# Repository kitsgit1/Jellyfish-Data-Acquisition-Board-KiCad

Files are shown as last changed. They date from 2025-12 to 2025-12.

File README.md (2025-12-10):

# Jellyfish Data Acquisition Board KiCad PCB Files
This is one of 3 repositories related to the Jellyfish Data Acquisition project. The goal is to build the hardware for a noninvasive electrode array capable of detecting neronal activity of small jellyfish, the firmware to digitize the signals and control the multiplexing of each pixel, and the software to control the system and graph the data.
| **Hardware** <br/> (You Are Here) | Firmware | Software |
| --- | --- | --- |
| <br/>https://github.com/kitsgit1/Jellyfish-Data-Acquisition-Board-KiCad |  <br/>https://github.com/kitsgit1/Jellyfish-Data-Acquisition-STM32 |  <br/>https://github.com/kitsgit1/Jellyfish-Data-Display-GUI |

# Hardware Documentation - Rev A
There are two boards that make up the assembly: the Electrode board and the Digitizer board.
## Jellyfish Electrode Board
The electrode board is responsible for interfacing with the jellyfish and multiplexing all pixels down to one wire using low charge-injection analog mux's. There is an optional path for a front-end buffer amplifier (non-inverting x2 gain for Rf = Rg). I/O consists of the Guard signal which drives the saltwater bath to the same potential as the op-amp reference voltage, the digital I/O to control the shift registers that select the correct pixel through setting all the multiplexers, and the single analog switched electrode signal.

## Jellyfish Digitizer Board
The digitizer board further amplifies the tiny signal from the electrode board into something the STM32's 10MHz/12-bit ADC can handle. The STM32 is also responsible for collecting, storing, and sending data to either the PC over USB or to an SD card.

Details to come...

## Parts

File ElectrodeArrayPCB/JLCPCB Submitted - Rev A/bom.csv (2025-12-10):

Designator | Footprint | Quantity | Value | LCSC Part #
BT1 | AMASS_XT30PW-M_1x02_P2.50mm_Horizontal | 1 | XT30PW-M30.G.Y | C431092
C1, C13, C14, C15, C18, C20, C22, C23, C24, C25, C30, C36, C38, C39, C41, C42, C43, C46, C51, C52, C53, C54, C55, C56, C59, C6, C63, C64, C68, C7, C70, C72, C73, C8, C9 | C_0402 | 35 | 100nF | C307331
C10, C11, C12, C16, C28, C67, C69, C71, C77, C79, C80 | C_1206 | 11 | 47uF | C96123
C17, C2, C21, C26, C29, C32, C4, C5, C76 | C_0805 | 9 | 10uF | C15850
C19, C44, C45, C78 | C_0402 | 4 | 10pF | C32949
C27, C3, C58, C81 | C_0402 | 4 | 4.7uF | C23733
C31, C37, C40, C57, C60 | C_0402 | 5 | 1uF | C52923
C61, C62 | C_0603 | 2 | 2.2uF | C23630
C65, C66 | C_0402 | 2 | 470pF | C1537
C74, C75 | C_0402 | 2 | 20pF | C1554
D1, D2, D3 | D_0603 | 3 | Red | C2286
FB1, FB2, FB3, FB4 | FB_0805 | 4 | ~ | C1015
J1 | PinHeader_2x05_P1.27mm_Vertical_SMD | 1 | HX PZ1.27-2x5P TP
J11, J3, J7, J8, J9 | SMA_Wurth_60312102114405_Vertical | 5 | KH-SMAK-SMT
J12 | PinHeader_1x03_P2.54mm_Vertical | 1 | 2.54-1*3PPin | C49257
J4 | microSD_HC_Molex_104031-0811 | 1 | 1040310811 | C585350
J6 | TYPE-C-SMD_HX-TYPE-C-16PIN | 1 | Connector, USB-TYPE-C-16P | C2927039
R1, R105, R19, R22, R32, R36, R47, R7, R89, R97, R98, R99 | R_0402 | 12 | 1kΩ | C11702
R10, R101, R107, R109, R11, R110, R111, R113, R114, R115, R116, R117, R120, R15, R16, R17, R18, R20, R21, R23, R24, R27, R28, R30, R31, R35, R37, R43, R44, R45, R52, R53, R55, R56, R57, R58, R71, R78, R85, R86, R87, R88, R92, R95, R96 | R_0402 | 45 | 0Ω | C17168
R100, R106, R13 | R_0402 | 3 | 49.9Ω | C25120
R102, R51, R8 | R_1206 | 3 | 0Ω | C17888
R103, R34, R4 | R_0402 | 3 | 10kΩ | C25744
R104, R94 | R_0603 | 2 | 5.1kΩ | C23186
R108 | R_0402 | 1 | 1Ω | C25086
R112 | R_0805 | 1 | 0Ω | C17477
R118, R3, R42, R46, R90, R91 | R_0402 | 6 | 100kΩ | C25741
R119, R2, R29, R49, R5, R54 | R_0603 | 6 | 270kΩ | C22965
R12 | R_0402 | 1 | 33kΩ | C25779
R14, R26 | R_0402 | 2 | 100Ω | C25076
R25, R50, R6 | R_0402 | 3 | 12kΩ | C25752
R33, R39 | R_0402 | 2 | 470kΩ | C25790
R38 | R_0402 | 1 | 220kΩ | C25767
R40, R93 | R_0402 | 2 | 1MΩ | C26083
R41, R59, R60, R61, R62, R63, R64 | R_0402 | 7 | 47kΩ | C25792
R48, R9 | R_0402 | 2 | 22kΩ | C25768
R65, R66, R67, R68, R69, R70, R72, R73, R74, R75, R76, R77, R79, R80, R81, R82, R83, R84 | R_0402 | 18 | 10Ω | C25077
S1 | SW_TS-1088-AR02016 | 1 | Tactile Button, 160gf | C720477
TP1, TP2, TP5, TP6, TP7 | TestPoint_Loop_D2.54mm_Drill1.5mm_Beaded | 5 | RH-5000 | C5277086
TP10, TP11, TP12, TP13, TP14, TP4, TP8, TP9 | TestPoint_Loop_D2.54mm_Drill1.5mm_Beaded | 8 | RH-5001 | C5199801
TP3 | TestPoint_Loop_D2.54mm_Drill1.5mm_Beaded | 1 | RH-5001
U1, U28, U4 | VSON-10-1EP_3x3mm_P0.5mm_EP1.65x2.4mm_ThermalVias | 3 | TPS7A9401DSCR | C5220127
U10 | SOT-23-5 | 1 | REF2033AIDDCR | C440747
U11 | SOIC-8_3.9x4.9mm_P1.27mm | 1 | LMP7721
U12 | SOT-23-5 | 1 | LMP7715
U14 | LFCSP-16-1EP_3x3mm_P0.5mm_EP1.3x1.3mm_ThermalVias | 1 | ADA4940-1ACPZ-R2 | C654337
U15 | LQFP-100_14x14mm_P0.5mm | 1 | STM32H7B0VBT6 | C730227
U16, U17 | SOT-23-6 | 2 | OPA847IDBVR | C160422
U19 | TSSOP-16_4.4x5mm_P0.65mm | 1 | TMUX1108PW
U2, U3 | PinHeader_03x03_0.1in | 2 | HX PZ2.54-3x3P ZZ | C32713290
U24, U25 | SOIC-8_3.9x4.9mm_P1.27mm | 2 | APS6404L-3SQR-SN | C5333729
U27 | SOIC-8_L4.9-W3.9-P1.27-LS6.0-BL | 1 | REF5025AIDR
U5 | SSOP-24_5.3x8.2mm_P0.65mm | 1 | 74HC4067PW,118 | C179326
U9 | SOT-23-3_L2.9-W1.6-P1.90-LS2.8-BR | 1 | CJ431 | C3113
X1 | OSC-SMD_4P-L3.2-W2.5-BL | 1 | X322516MLB4SI | C13738

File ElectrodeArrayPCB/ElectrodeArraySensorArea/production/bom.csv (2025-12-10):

Designator | Footprint | Quantity | Value | LCSC Part #
C1, C11, C13, C14, C16, C19, C21, C5, C6, C8, C9 | C_0402 | 11 | 100nF | C307331
C10, C12, C15, C17, C18, C3, C4, C7 | C_0402 | 8 | 47pF | C1567
C2 | C_0805 | 1 | 10uF | C15850
C20 | C_1206 | 1 | 47uF | C96123
C78 | C_0402 | 1 | 10pF | C32949
FB1 | FB_0805 | 1 | ~ | C1015
R20, R31, R9 | R_0402 | 3 | 0Ω | C17168
R4 | R_0402 | 1 | 10kΩ | C25744
U1 | Electrode_Array_64_Square | 1 | ~
U10, U11, U12, U13, U14, U15, U16, U17, U18 | UQFN-16_1.8x2.6mm_P0.4mm | 9 | TMUX1108RSVR
U19, U20, U21, U22, U8, U9 | PinHeader_1x03_P2.54mm_Vertical | 6 | DS1023-1x3SF11 | C7509516
U2, U3, U4, U5, U6 | DHVQFN-16-1EP_2.5x3.5mm_P0.5mm_EP1x2mm | 5 | SN74LV595ABQBR | C7083313
U7 | SOIC-8_3.9x4.9mm_P1.27mm | 1 | LMP7721

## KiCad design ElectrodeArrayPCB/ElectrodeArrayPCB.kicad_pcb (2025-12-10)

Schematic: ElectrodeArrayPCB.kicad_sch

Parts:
BT1: XT30PW-M30.G.Y; AMASS_XT30PW-M_1x02_P2.50mm_Horizontal; LCSC C431092
C1, C6, C7, C8, C9, C13, C14, C15, C18, C20, C22, C23, C24, C25, C30, C36, C38, C39, C41, C42, C43, C46, C51, C52, C53, C54, C55, C56, C59, C63, C64, C68, C70, C72, C73: 100nF; C_0402; Voltage Rated 50V; Tolerance ±10%; Part CL05B104KB54PNC; LCSC C307331
C2, C4, C5, C17, C21, C26, C29, C32, C76: 10uF; C_0805; Voltage Rated 25V; Tolerance ±10%; Part CL21A106KAYNNNE; LCSC C15850
C3, C27, C58, C81: 4.7uF; C_0402; Voltage Rated 10V; Tolerance ±20%; Part CL05A475MP5NRNC; LCSC C23733
C10, C11, C12, C16, C28, C67, C69, C71, C77, C79, C80: 47uF; C_1206; Voltage Rated 10V; Tolerance ±20%; Part CL31A476MPHNNNE; LCSC C96123
C19, C44, C45, C78: 10pF; C_0402; Voltage Rated 50V; Tolerance ±5%; Part CL05C100JB5NNNC; LCSC C32949
C31, C37, C40, C57, C60: 1uF; C_0402; Voltage Rated 25V; Tolerance ±10%; Part CL05A105KA5NQNC; LCSC C52923
C61, C62: 2.2uF; C_0603; Voltage Rated 16V; Tolerance ±10%; Part CL10A225KO8NNNC; LCSC C23630
C65, C66: 470pF; C_0402; Voltage Rated 50V; Tolerance ±10%; Part 0402B471K500NT; LCSC C1537
C74, C75: 20pF; C_0402; Voltage Rated 50V; Tolerance ±5%; Part 0402CG200J500NT; LCSC C1554
D1, D2, D3: Red; D_0603; Part KT-0603R; LCSC C2286
FB1, FB2, FB3, FB4: FB_0805; Current Rating 800mA; Tolerance ±25%; Part GZ2012D101TF; LCSC C1015
J1: HX PZ1.27-2x5P TP; PinHeader_2x05_P1.27mm_Vertical_SMD
J2, J10: Conn_01x10_Pin; Electrode_Line_8_Test
J3, J7, J8, J9, J11: KH-SMAK-SMT; SMA_Wurth_60312102114405_Vertical
J4: 1040310811; microSD_HC_Molex_104031-0811; LCSC C585350
J5: Conn_ARM_SWD_TagConnect_TC2030; Tag-Connect_TC2030-IDC-FP_2x03_P1.27mm_Vertical
J6: Connector, USB-TYPE-C-16P; TYPE-C-SMD_HX-TYPE-C-16PIN; LCSC C2927039
J12: 2.54-1*3PPin; PinHeader_1x03_P2.54mm_Vertical; LCSC C49257
P1, P2: Jumper Shunt; LCSC C2758458
R1, R7, R19, R22, R32, R36, R47, R89, R97, R98, R99, R105: 1kΩ; R_0402; Overload Voltage (Max) 50V; Tolerance ±1%; Part 0402WGF1001TCE; LCSC C11702
R2, R5, R29, R49, R54, R119: 270kΩ; R_0603; Overload Voltage (Max) 75V; Tolerance ±1%; Part 0603WAF2703T5E; LCSC C22965
R3, R42, R46, R90, R91, R118: 100kΩ; R_0402; Overload Voltage (Max) 50V; Tolerance ±1%; Part 0402WGF1003TCE; LCSC C25741
R4, R34, R103: 10kΩ; R_0402; Overload Voltage (Max) 50V; Tolerance ±1%; Part 0402WGF1002TCE; LCSC C25744
R6, R25, R50: 12kΩ; R_0402; Overload Voltage (Max) 50V; Tolerance ±1%; Part 0402WGF1202TCE; LCSC C25752
R8, R51, R102: 0Ω; R_1206; Overload Voltage (Max) 200V; Tolerance ±1%; Part 1206W4F0000T5E; LCSC C17888
R9, R48: 22kΩ; R_0402; Overload Voltage (Max) 50V; Tolerance ±1%; Part 0402WGF2202TCE; LCSC C25768
R10, R11, R17, R18, R20, R21, R23, R27, R28, R30, R31, R35, R37, R44, R45, R53, R55, R58, R71, R78, R85, R86, R87, R88, R92, R95, R107, R109, R110, R111, R113, R114, R115, R120: 0Ω; R_0402; Overload Voltage (Max) 50V; Tolerance ±1%; Part 0402WGF0000TCE; LCSC C17168
R12: 33kΩ; R_0402; Overload Voltage (Max) 50V; Tolerance ±1%; Part 0402WGF3302TCE; LCSC C25779
R13, R100, R106: 49.9Ω; R_0402; Overload Voltage (Max) 50V; Tolerance ±1%; Part 0402WGF499JTCE; LCSC C25120
R14, R26: 100Ω; R_0402; Overload Voltage (Max) 50V; Tolerance ±1%; Part 0402WGF1000TCE; LCSC C25076
R15, R16, R24, R43, R52, R56, R57, R96, R101, R116, R117: 0Ω; R_0402; Overload Voltage (Max) 50V; Tolerance ±1%; Part 0402WGF0000TCE; LCSC C17168; not fitted
R33, R39: 470kΩ; R_0402; Overload Voltage (Max) 50V; Tolerance ±1%; Part 0402WGF4703TCE; LCSC C25790
R38: 220kΩ; R_0402; Overload Voltage (Max) 50V; Tolerance ±1%; Part 0402WGF2203TCE; LCSC C25767
R40, R93: 1MΩ; R_0402; Overload Voltage (Max) 50V; Tolerance ±1%; Part 0402WGF1004TCE; LCSC C26083
R41, R59, R60, R61, R62, R63, R64: 47kΩ; R_0402; Overload Voltage (Max) 50V; Tolerance ±1%; Part 0402WGF4702TCE; LCSC C25792
R65, R66, R67, R68, R69, R70, R72, R73, R74, R75, R76, R77, R79, R80, R81, R82, R83, R84: 10Ω; R_0402; Overload Voltage (Max) 50V; Tolerance ±1%; Part 0402WGF100JTCE; LCSC C25077
R94, R104: 5.1kΩ; R_0603; Overload Voltage (Max) 75V; Tolerance ±1%; Part 0603WAF5101T5E; LCSC C23186
R108: 1Ω; R_0402; Overload Voltage (Max) 50V; Tolerance ±1%; Part 0402WGF100KTCE; LCSC C25086
R112: 0Ω; R_0805; Overload Voltage (Max) 150V; Tolerance ±1%; Part 0805W8F0000T5E; LCSC C17477
S1: Tactile Button, 160gf; SW_TS-1088-AR02016; Voltage Rating (Dc) 12V; Part TS-1088-AR02016; LCSC C720477
TP1, TP2, TP5, TP6, TP7: RH-5000; TestPoint_Loop_D2.54mm_Drill1.5mm_Beaded; LCSC C5277086
TP3: RH-5001; TestPoint_Loop_D2.54mm_Drill1.5mm_Beaded
TP4, TP8, TP9, TP10, TP11, TP12, TP13, TP14: RH-5001; TestPoint_Loop_D2.54mm_Drill1.5mm_Beaded; LCSC C5199801
U1, U4, U28: TPS7A9401DSCR; VSON-10-1EP_3x3mm_P0.5mm_EP1.65x2.4mm_ThermalVias; LCSC C5220127
U2, U3: HX PZ2.54-3x3P ZZ; PinHeader_03x03_0.1in; LCSC C32713290
U5: 74HC4067PW,118; SSOP-24_5.3x8.2mm_P0.65mm; LCSC C179326
U9: CJ431; SOT-23-3_L2.9-W1.6-P1.90-LS2.8-BR; Output Voltage 2.5V~36V; Tolerance ±0.5%; Part CJ431; LCSC C3113
U10: REF2033AIDDCR; SOT-23-5; LCSC C440747
U11: LMP7721; SOIC-8_3.9x4.9mm_P1.27mm
U12: LMP7715; SOT-23-5
U14: ADA4940-1ACPZ-R2; LFCSP-16-1EP_3x3mm_P0.5mm_EP1.3x1.3mm_ThermalVias; LCSC C654337
U15: STM32H7B0VBT6; LQFP-100_14x14mm_P0.5mm; LCSC C730227
U16, U17: OPA847IDBVR; SOT-23-6; LCSC C160422
U19: TMUX1108PW; TSSOP-16_4.4x5mm_P0.65mm
U24, U25: APS6404L-3SQR-SN; SOIC-8_3.9x4.9mm_P1.27mm; LCSC C5333729
U27: REF5025AIDR; SOIC-8_L4.9-W3.9-P1.27-LS6.0-BL
X1: X322516MLB4SI; OSC-SMD_4P-L3.2-W2.5-BL; Frequency Tolerance ±10ppm; Part X322516MLB4SI; LCSC C13738

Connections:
+3.3V: R8.2, R52.2, R112.1
+3.3VA: FB2.2, R51.2
+5V: C9.1, C16.1, R14.2, R18.1, R19.1, R27.2, R30.2, R37.2, R44.1, R45.1, R85.2, R102.2, R109.2, U3.1
/MCU_VDD33: C51.1, C52.1, C53.1, C54.1, C55.1, C56.1, C57.1, C58.1, R58.1, R71.1, R78.1, R89.1, R92.2, R112.2, U15.6 (VBAT), U15.11 (VDD), U15.27 (VDD), U15.50 (VDD), U15.75 (VDD), U15.100 (VDD)
/PA11_USB_DM: J6.A7 (D-), J6.B7 (D-), U15.70 (PA11)
/PA12_USB_DP: J6.A6 (D+), J6.B6 (D+), U15.71 (PA12)
/USART1_RX: J12.2, U15.54 (PB15)
/USART1_TX: J12.1, U15.53 (PB14)
/amp_inverting_input: R34.1, U12.3 (+)
/battery: BT1.1 (+), C20.1, C21.1, FB1.1, FB3.1, FB4.1
/grd_drv_out: R26.2, U12.1, U12.4 (-)
/ldo_3v3: C10.1, C17.1, C18.1, R5.2, R8.1, TP2.1, U1.8 (SNS), U1.9 (OUT), U1.10 (OUT)
/ldo_3v3A: C28.1, C29.1, C30.1, R49.2, R51.1, TP7.1, U4.8 (SNS), U4.9 (OUT), U4.10 (OUT)
/ldo_5v: C4.1, C7.1, C80.1, R54.2, R102.1, TP1.1, U28.8 (SNS), U28.9 (OUT), U28.10 (OUT)
/vbat_post_fb5: C5.1, C6.1, FB3.2, R1.2, R119.1, U28.1 (IN), U28.2 (IN)
/vbat_post_fb33: C1.1, C2.1, FB1.2, R2.1, R7.1, U1.1 (IN), U1.2 (IN)
/vbat_post_fb33A: C22.1, C26.1, FB4.2, R29.1, R47.1, U4.1 (IN), U4.2 (IN)
ADC_N: R100.2, R114.1
ADC_P: R106.2, R113.1
GND: BT1.2 (-), C1.2, C2.2, C3.2, C4.2, C5.2, C6.2, C7.2, C8.2, C9.2, C10.2, C11.2, C12.2, C13.2, C14.2, C15.2, C16.2, C17.2, C18.2, C19.1, C20.2, C21.2, C22.2, C23.2, C24.2, C25.2, C26.2, C27.2, C28.2, C29.2, C30.2, C31.2, C32.2, C36.2, C37.2, C38.2, C39.2, C40.2, C41.2, C42.1, C43.2, C44.2, C45.1, C46.2, C51.2, C52.2, C53.2, C54.2, C55.2, C56.2, C57.2, C58.2, C59.2, C60.2, C61.2, C62.2, C63.2, C64.2, C68.2, C69.2, C70.2, C71.2, C72.2, C73.2, C76.2, C77.2, C79.2, C80.2, C81.2, J3.2 (Ext), J4.6 (VSS), J4.9 (SHIELD), J5.5 (GND), J6.A12B1 (GND), J6.B12A1 (GND), J7.2 (Ext), J8.2 (Ext), J9.2 (Ext), J11.2 (Ext), J12.3, R3.2, R6.2, R9.2, R12.2, R13.2, R15.2, R17.1, R24.1, R25.2, R46.2, R48.2, R50.2, R93.2, R94.2, R104.2, R107.2, R108.2, R116.1, R117.2, R118.2, S1.1 (A), TP3.1, TP4.1, TP8.1, TP9.1, TP10.1, TP11.1, U1.6 (GND), U1.11 (EPAD), U2.1, U2.3, U2.7, U2.9, U3.2, U3.4, U3.5, U4.6 (GND), U4.11 (EPAD), U5.12 (GND), U5.13 (S3), U5.15 (~E), U9.3 (AN), U10.2 (GND), U11.3 (V-), U12.2 (V-), U14.13 (-Vs), U14.14 (-Vs), U14.15 (-Vs), U14.16 (-Vs), U14.17 (EP), U15.10 (VSS), U15.19 (VSSA), U15.26 (VSS), U15.49 (VSS), U15.74 (VSS), U15.99 (VSS), U16.2 (V-), U17.2 (V-), U19.3 (VSS), U19.14 (GND), U24.4 (VSS), U25.4 (VSS), U27.4 (GND), U28.6 (GND), U28.11 (EPAD), X1.2 (GND), X1.4 (GND)
unnamed: C14.1, C67.1, P2.2, R23.1, R53.1, R101.2
unnamed: C41.1, C76.1, R85.1, R95.2, U14.5 (+Vs), U14.6 (+Vs), U14.7 (+Vs), U14.8 (+Vs)
unnamed: C61.1, C62.1, C63.1, C64.1, U15.48 (VCAP), U15.73 (VCAP)
unnamed: C65.2, C66.1, R107.1
unnamed: C67.2, R108.1
unnamed: D1.2, R1.1
unnamed: D2.2, R7.2
unnamed: D3.2, R47.2
unnamed: J1.1, R40.2, R43.2
unnamed: J1.3, R39.2
unnamed: J1.5, R38.2
unnamed: J1.7, R42.2
unnamed: J1.9, P1.1, R41.2
unnamed: J1.2, J1.4, J1.6, J1.8, J1.10, P1.2, R43.1, R55.1, R56.1, R105.1
unnamed: J2.1, U5.9 (I0)
unnamed: J2.2, U5.8 (I1)
unnamed: J2.3, U5.7 (I2)
unnamed: J2.4, U5.6 (I3)
unnamed: J2.5, U5.5 (I4)
unnamed: J2.6, U5.4 (I5)
unnamed: J2.7, U5.3 (I6)
unnamed: J2.8, U5.2 (I7)
unnamed: J2.9, J8.1 (In)
unnamed: J3.1 (In), R20.1
unnamed: J4.5 (CLK), R64.2, R69.2
unnamed: J4.3 (CMD), R63.2, R70.2
unnamed: J4.7 (DAT0), R60.2, R65.2
unnamed: J4.8 (DAT1), R61.2, R66.2
unnamed: J4.1 (DAT2), R59.2, R67.2
unnamed: J4.2 (DAT3/CD), R62.2, R68.2
unnamed: C36.1, J4.4 (VDD), R58.2, R59.1, R60.1, R61.1, R62.1, R63.1, R64.1
unnamed: J5.4 (SWCLK), R87.1
unnamed: J5.2 (SWDIO), R88.2
unnamed: J5.1 (VCC), R91.1, R92.1
unnamed: J5.3 (~RESET), R86.1
unnamed: J6.A5 (CC1), R104.1
unnamed: J6.B5 (CC2), R94.1
unnamed: C46.1, J6.S1 (SHIELD), R93.1
unnamed: J6.A9B4 (VBUS), J6.B9A4 (VBUS), R96.1
unnamed: J7.1 (In), R120.2
unnamed: C19.2, J9.1 (In), R10.2, R11.2
unnamed: J10.1, U19.4 (S1)
unnamed: J10.2, U19.5 (S2)
unnamed: J10.3, U19.6 (S3)
unnamed: J10.4, U19.7 (S4)
unnamed: J10.5, U19.9 (S8)
unnamed: J10.6, U19.10 (S7)
unnamed: J10.7, U19.11 (S6)
unnamed: J10.8, U19.12 (S5)
unnamed: J2.10, J10.9
unnamed: J10.10, R13.1
unnamed: J11.1 (In), R28.2
unnamed: R21.2, U2.5
unnamed: R28.1, R55.2, U17.1
unnamed: R56.2, R57.1
unnamed: R17.2, R52.1, R103.1
unnamed: R33.2, R35.2, R57.2, R115.1
unnamed: R115.2, U16.1
unnamed: C42.2, R90.1, S1.2 (B)
unnamed: R2.2, R3.1, U1.3 (EN_UV)
unnamed: R5.1, R6.1, U1.5 (FB_PG)
unnamed: C3.1, R9.1, U1.7 (NR/SS)
unnamed: D2.1, U1.4 (PG)
unnamed: R29.2, R46.1, U4.3 (EN_UV)
unnamed: R49.1, R50.1, U4.5 (FB_PG)
unnamed: C27.1, R48.1, U4.7 (NR/SS)
unnamed: D3.1, U4.4 (PG)
unnamed: R10.1, U5.1 (COM)
unnamed: C8.1, R44.2, U5.24 (VCC)
unnamed: R16.1, R19.2, R101.1, U9.2 (CAT)
unnamed: R15.1, R16.2, U9.1 (REF)
unnamed: C70.1, C71.1, R109.1, U10.3 (EN), U10.4 (IN)
unnamed: C72.1, R110.1, U10.1 (Vbias)
unnamed: C73.1, R111.1, U10.5 (Vref)
unnamed: R20.2, U11.1 (IN+)
unnamed: C78.1, R4.1, R22.1, R34.2, U11.8 (IN-)
unnamed: C11.1, C12.1, C13.1, R27.1, U11.6 (V+)
unnamed: C78.2, R4.2, R31.2, U11.4 (Vout)
unnamed: C15.1, C77.1, C79.1, R14.1, U12.5 (V+)
unnamed: C74.2, R99.2, U14.4 (+FB)
unnamed: C75.1, R97.1, R105.2, U14.2 (+IN)
unnamed: R113.2, U14.10 (+OUT)
unnamed: C75.2, R97.2, U14.1 (-FB)
unnamed: C74.1, R98.2, R99.1, U14.3 (-IN)
unnamed: R114.2, U14.11 (-OUT)
unnamed: R110.2, U14.9 (VOCM)
unnamed: R95.1, U14.12 (~DISABLE)
unnamed: R103.2, U15.94 (BOOT0)
unnamed: R96.2, U15.68 (PA9)
unnamed: R88.1, R91.2, U15.72 (PA13)
unnamed: R87.2, U15.76 (PA14)
unnamed: C65.1, R100.1, U15.17 (PC2_C)
unnamed: C66.2, R106.1, U15.18 (PC3_C)
unnamed: R65.1, U15.65 (PC8)
unnamed: R66.1, U15.66 (PC9)
unnamed: R67.1, U15.78 (PC10)
unnamed: R68.1, U15.79 (PC11)
unnamed: R69.1, U15.80 (PC12)
unnamed: R81.1, U15.58 (PD11)
unnamed: R82.1, U15.59 (PD12)
unnamed: R84.1, U15.60 (PD13)
unnamed: R73.2, U15.37 (PE7)
unnamed: R74.2, U15.38 (PE8)
unnamed: R75.2, U15.39 (PE9)
unnamed: R76.2, U15.40 (PE10)
unnamed: R72.1, R79.1, U15.41 (PE11)
unnamed: C45.2, U15.12 (PH0), X1.3 (OSC)
unnamed: C44.1, U15.13 (PH1), X1.1 (OSC)
unnamed: C59.1, C60.1, FB2.1, U15.21 (VDDA)
unnamed: R21.1, R31.1, R120.1, U16.3 (+)
unnamed: R32.1, R33.1, U16.4 (-)
unnamed: C23.1, R30.1, U16.6 (V+)
unnamed: R116.2, U16.5 (~DIS)
unnamed: R35.1, U17.3 (+)
unnamed: R36.1, R38.1, R39.1, R40.1, R41.1, R42.1, U17.4 (-)
unnamed: C24.1, R37.1, U17.6 (V+)
unnamed: R117.1, U17.5 (~DIS)
unnamed: R11.1, U19.8 (D)
unnamed: C25.1, R45.2, U19.2 (EN), U19.13 (VDD)
unnamed: R77.2, U24.6 (SCLK)
unnamed: R75.1, U24.3 (SIO2)
unnamed: R76.1, U24.7 (SIO3)
unnamed: R73.1, U24.5 (SI/SIO0)
unnamed: R74.1, U24.2 (SO/SIO1)
unnamed: C37.1, C38.1, R71.2, U24.8 (VDD)
unnamed: R72.2, U24.1 (~CE)
unnamed: R80.1, U25.6 (SCLK)
unnamed: R83.2, U25.3 (SIO2)
unnamed: R84.2, U25.7 (SIO3)
unnamed: R81.2, U25.5 (SI/SIO0)
unnamed: R82.2, U25.2 (SO/SIO1)
unnamed: C39.1, C40.1, R78.2, U25.8 (VDD)
unnamed: R79.2, U25.1 (~CE)
unnamed: C31.1, C32.1, U27.5 (Trim/NR)
unnamed: C68.1, C69.1, R18.2, U27.2 (Vin)
unnamed: P2.1, R53.2, U27.6 (Vout)
unnamed: R118.1, R119.2, U28.3 (EN_UV)
unnamed: R25.1, R54.1, U28.5 (FB_PG)
unnamed: C81.1, R12.1, U28.7 (NR/SS)
unnamed: D1.1, U28.4 (PG)
PA7_OCTASPI_P1_IO2: R83.1, U15.31 (PA7)
PB2_OCTASPI_P1_CLK: R77.1, R80.2, U15.36 (PB2)
PD2_SDMMC1_CMD: R70.1, U15.83 (PD2)
STM32_RSTn: C43.1, R86.2, R89.2, R90.2, U15.14 (NRST)
Shift_OEb: U3.3, U15.28 (PA4)
Shift_RCLK: U3.6, U15.29 (PA5)
Shift_SER: U3.7, U15.33 (PC5)
Shift_SRCLK: U3.9, U15.32 (PC4)
Shift_SRCLRb: U3.8, U15.30 (PA6)
VCM_Guard_2.5V: R22.2, R23.2, R24.2, R32.2, R36.2, R98.1, TP5.1
Vref: R111.2, U15.20 (VREF+)
guard_ring: R26.1, TP6.1, U2.2, U2.4, U2.6, U2.8, U11.2 (GRD), U11.7 (GRD)
s0: TP14.1, U5.10 (S0), U15.1 (PE2), U19.1 (A0)
s1: TP13.1, U5.11 (S1), U15.2 (PE3), U19.16 (A1)
s2: TP12.1, U5.14 (S2), U15.3 (PE4), U19.15 (A2)

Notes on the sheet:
VCM=2.5V here
Alternate ram possibilities: APS12808L-3OBM-BA (128Mb OSPI, mouser) S70KL1281 (128Mb hyperam/OSPI, obsolete) W956A8MBYA5I (64Mb, LCSC stock, hyperbus) S66/67WVO32M8DALL/BLL (256Mb, OSPI)
16MHz
1.65V CM
1ms per AP spike (really 2-10ms) 20 points per spike -> 50us per sample -> 20kHz sample rate. 64 electrodes -> 1.28MHz sample rate. 4096 electrodes -> 81.92MHz sample rate, single CH. For now, pick ADC for 2MHz. High bit count.
DS Table 23

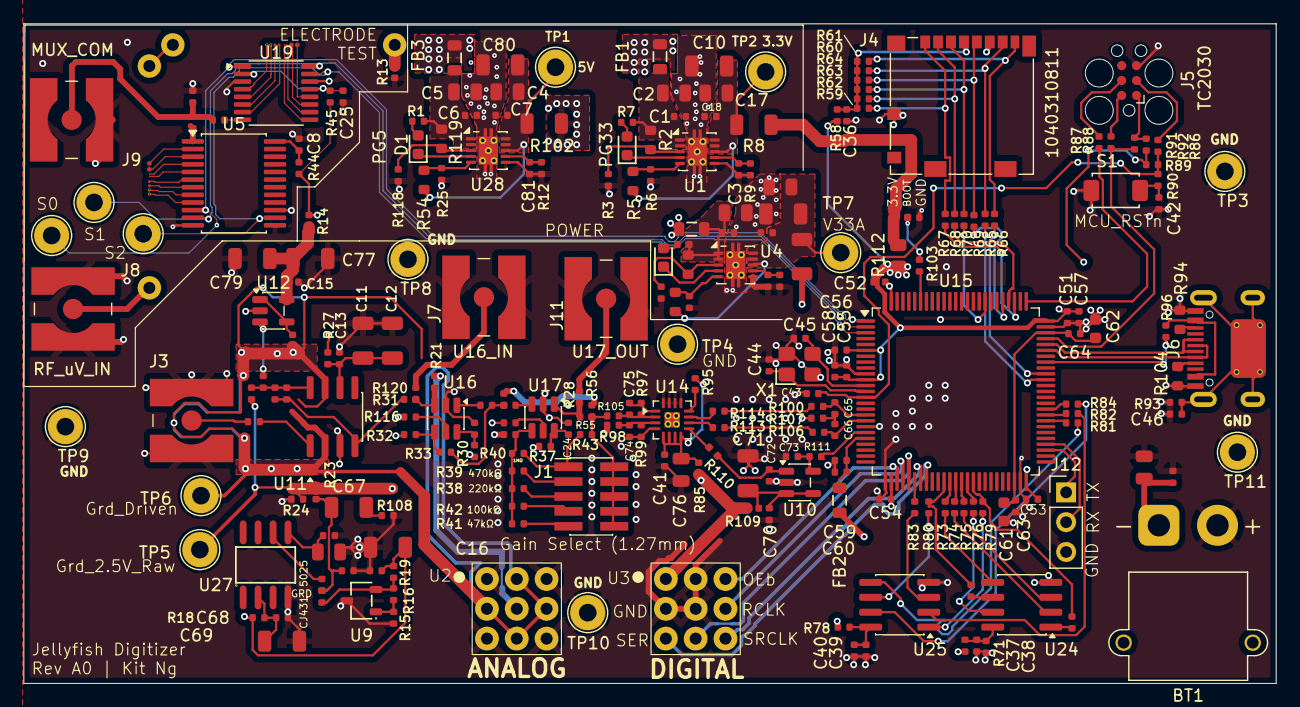
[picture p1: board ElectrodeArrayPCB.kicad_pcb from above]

Board: 4 copper layers, 106.7 x 56.2 mm, 248 parts (0 on the bottom side), 175 nets.

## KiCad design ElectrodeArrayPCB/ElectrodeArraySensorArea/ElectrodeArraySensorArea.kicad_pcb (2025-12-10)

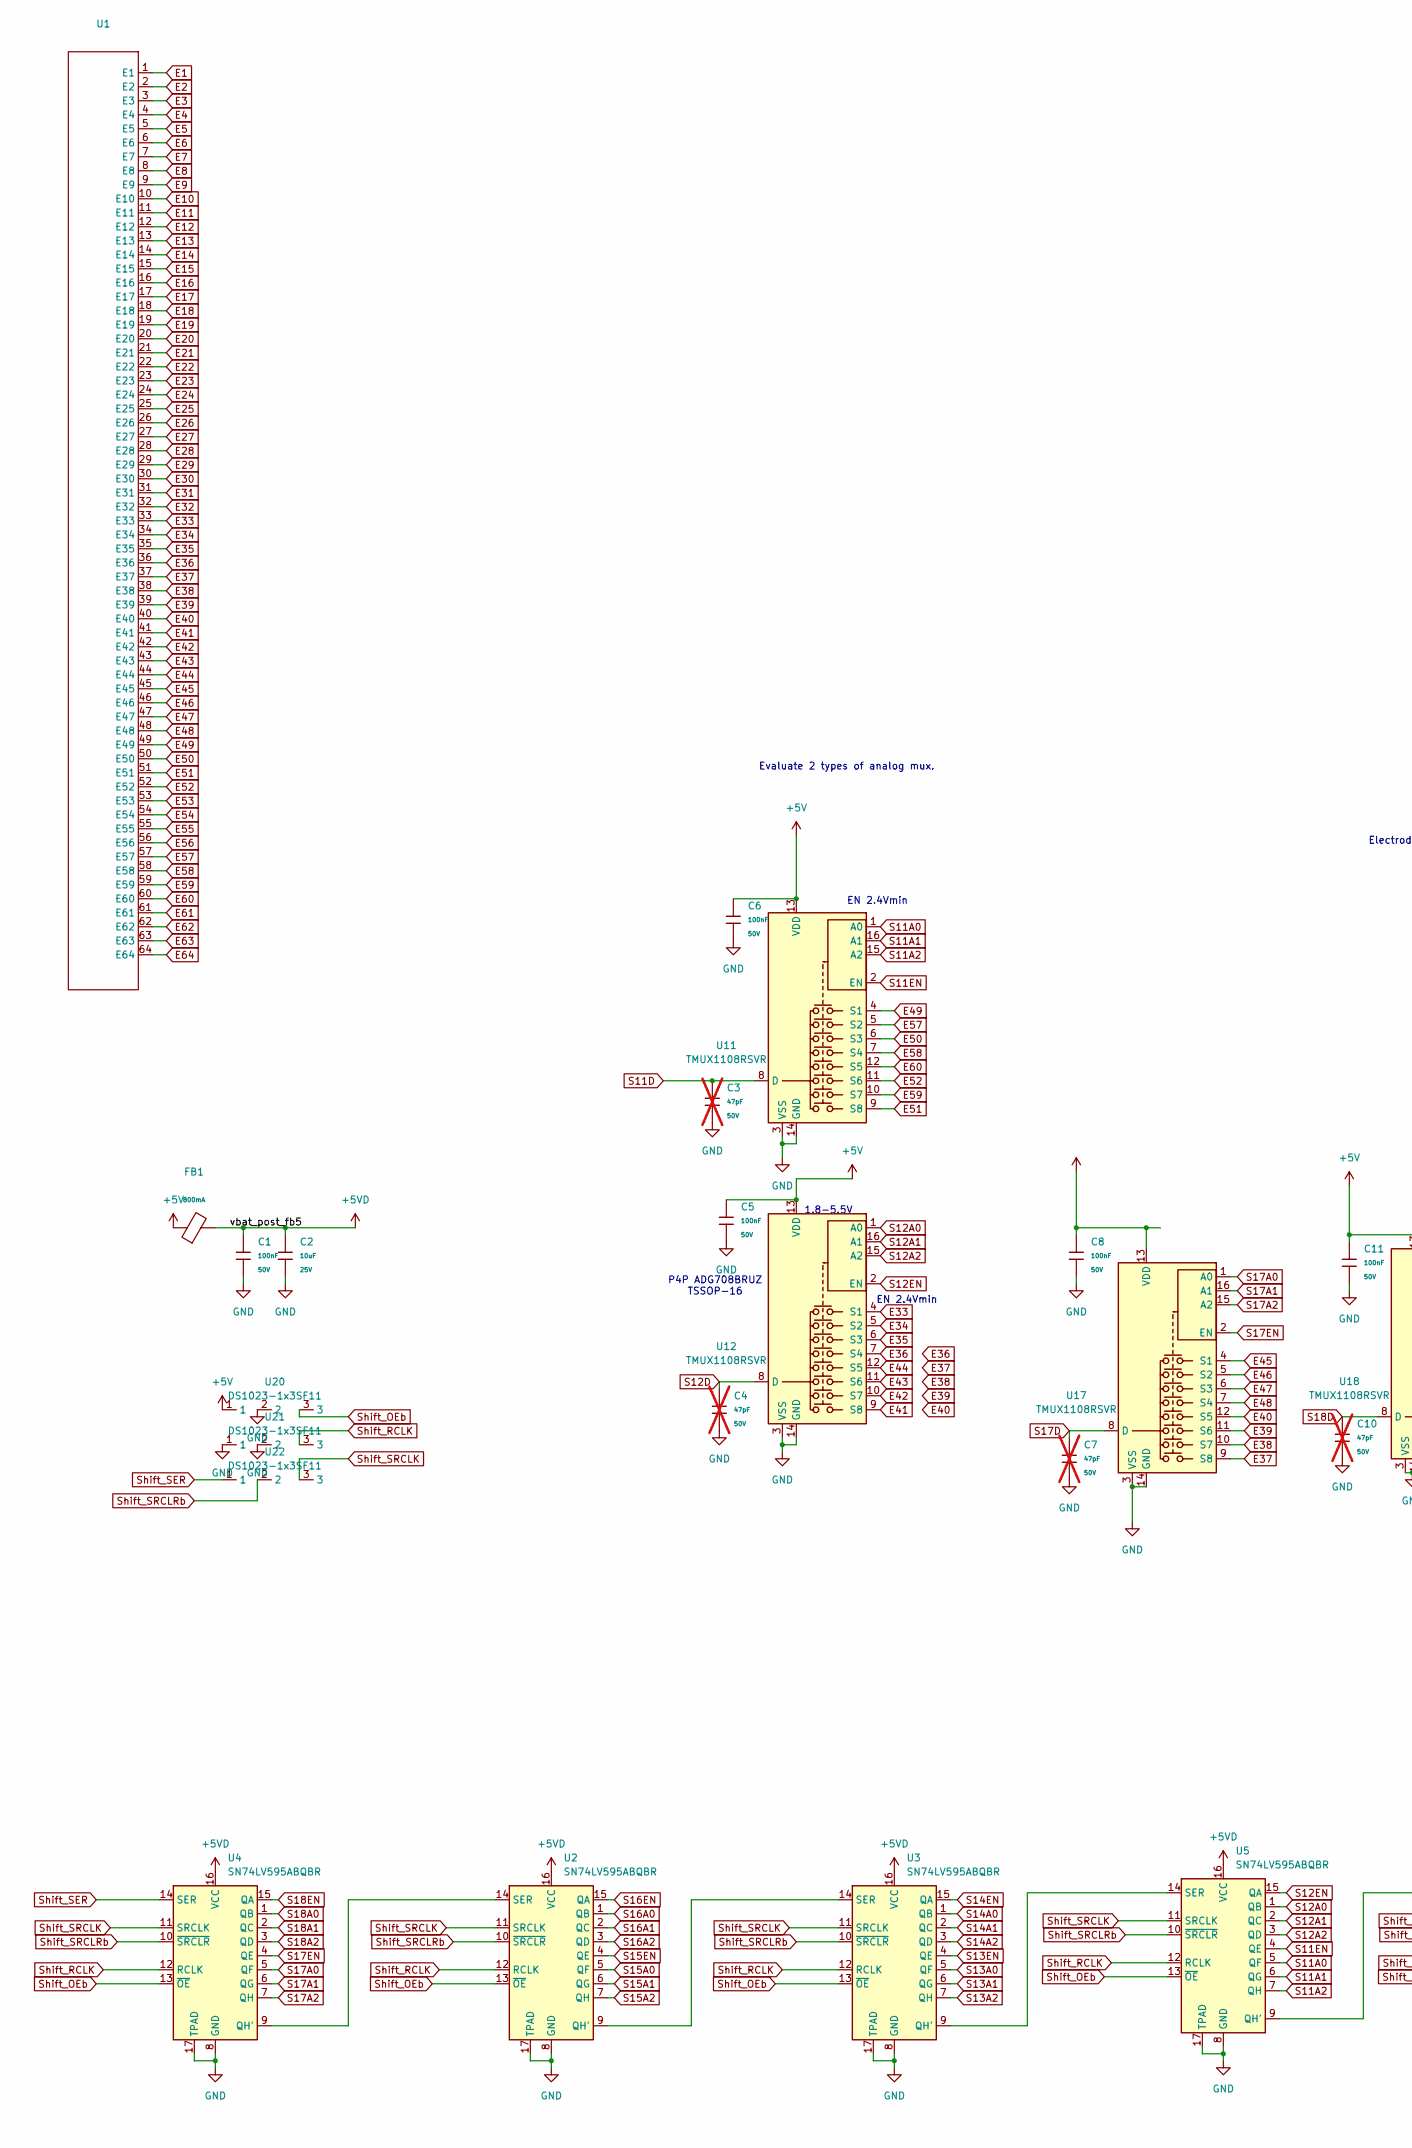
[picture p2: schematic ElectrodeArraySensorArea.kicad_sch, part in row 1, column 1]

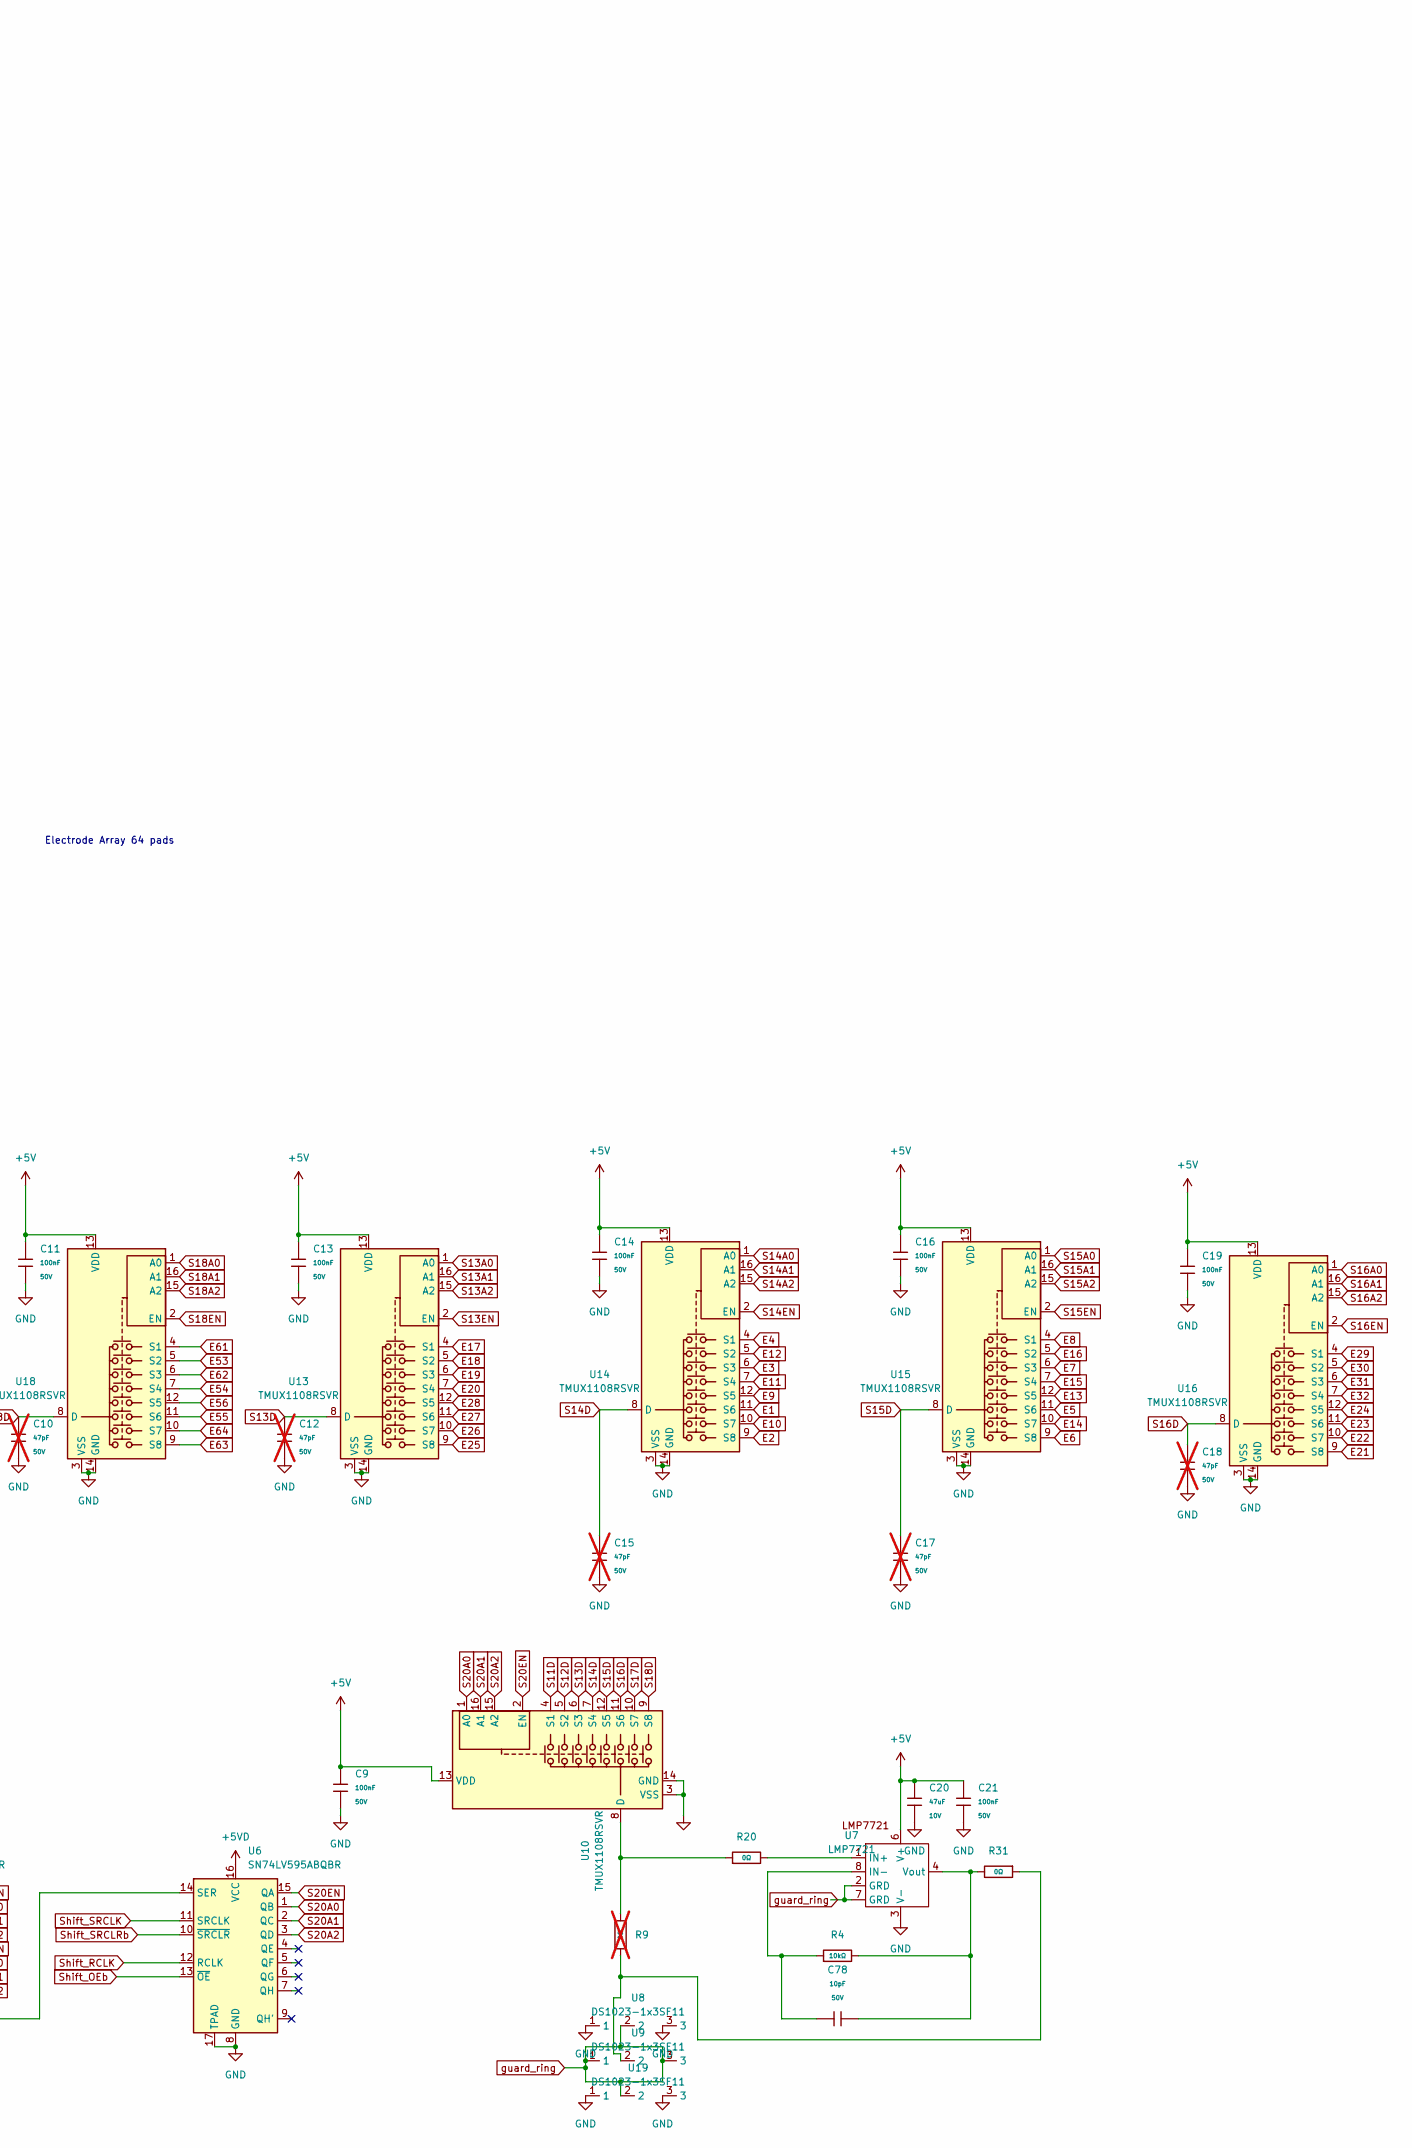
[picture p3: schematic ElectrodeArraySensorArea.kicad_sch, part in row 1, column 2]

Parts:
C1, C5, C6, C8, C9, C11, C13, C14, C16, C19, C21: 100nF; C_0402; Voltage Rated 50V; Tolerance ±10%; Part CL05B104KB54PNC; LCSC C307331
C2: 10uF; C_0805; Voltage Rated 25V; Tolerance ±10%; Part CL21A106KAYNNNE; LCSC C15850
C3, C4, C7, C10, C12, C15, C17, C18: 47pF; C_0402; Voltage Rated 50V; Tolerance ±5%; Part 0402CG470J500NT; LCSC C1567; not fitted
C20: 47uF; C_1206; Voltage Rated 10V; Tolerance ±20%; Part CL31A476MPHNNNE; LCSC C96123
C78: 10pF; C_0402; Voltage Rated 50V; Tolerance ±5%; Part CL05C100JB5NNNC; LCSC C32949
FB1: FB_0805; Current Rating 800mA; Tolerance ±25%; Part GZ2012D101TF; LCSC C1015
R4: 10kΩ; R_0402; Overload Voltage (Max) 50V; Tolerance ±1%; Part 0402WGF1002TCE; LCSC C25744
R9: 0Ω; R_0402; Overload Voltage (Max) 50V; Tolerance ±1%; Part 0402WGF0000TCE; LCSC C17168; not fitted
R20, R31: 0Ω; R_0402; Overload Voltage (Max) 50V; Tolerance ±1%; Part 0402WGF0000TCE; LCSC C17168
U1: Electrode_Array_64_Square
U2, U3, U4, U5, U6: SN74LV595ABQBR; DHVQFN-16-1EP_2.5x3.5mm_P0.5mm_EP1x2mm; LCSC C7083313
U7: LMP7721; SOIC-8_3.9x4.9mm_P1.27mm
U8, U9, U19, U20, U21, U22: DS1023-1x3SF11; PinHeader_1x03_P2.54mm_Vertical; LCSC C7509516
U10, U11, U12, U13, U14, U15, U16, U17, U18: TMUX1108RSVR; UQFN-16_1.8x2.6mm_P0.4mm

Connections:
+5V: C5.1, C6.1, C8.1, C9.1, C11.1, C13.1, C14.1, C16.1, C19.1, C20.1, C21.1, FB1.1, U7.6 (V+), U10.13 (VDD), U11.13 (VDD), U12.13 (VDD), U13.13 (VDD), U14.13 (VDD), U15.13 (VDD), U16.13 (VDD), U17.13 (VDD), U18.13 (VDD), U20.1
+5VD: C1.1, C2.1, FB1.2, U2.16 (VCC), U3.16 (VCC), U4.16 (VCC), U5.16 (VCC), U6.16 (VCC)
E1: U1.1 (E1), U14.11 (S6)
E2: U1.2 (E2), U14.9 (S8)
E3: U1.3 (E3), U14.6 (S3)
E4: U1.4 (E4), U14.4 (S1)
E5: U1.5 (E5), U15.11 (S6)
E6: U1.6 (E6), U15.9 (S8)
E7: U1.7 (E7), U15.6 (S3)
E8: U1.8 (E8), U15.4 (S1)
E9: U1.9 (E9), U14.12 (S5)
E10: U1.10 (E10), U14.10 (S7)
E11: U1.11 (E11), U14.7 (S4)
E12: U1.12 (E12), U14.5 (S2)
E13: U1.13 (E13), U15.12 (S5)
E14: U1.14 (E14), U15.10 (S7)
E15: U1.15 (E15), U15.7 (S4)
E16: U1.16 (E16), U15.5 (S2)
E17: U1.17 (E17), U13.4 (S1)
E18: U1.18 (E18), U13.5 (S2)
E19: U1.19 (E19), U13.6 (S3)
E20: U1.20 (E20), U13.7 (S4)
E21: U1.21 (E21), U16.9 (S8)
E22: U1.22 (E22), U16.10 (S7)
E23: U1.23 (E23), U16.11 (S6)
E24: U1.24 (E24), U16.12 (S5)
E25: U1.25 (E25), U13.9 (S8)
E26: U1.26 (E26), U13.10 (S7)
E27: U1.27 (E27), U13.11 (S6)
E28: U1.28 (E28), U13.12 (S5)
E29: U1.29 (E29), U16.4 (S1)
E30: U1.30 (E30), U16.5 (S2)
E31: U1.31 (E31), U16.6 (S3)
E32: U1.32 (E32), U16.7 (S4)
E33: U1.33 (E33), U12.4 (S1)
E34: U1.34 (E34), U12.5 (S2)
E35: U1.35 (E35), U12.6 (S3)
E36: U1.36 (E36), U12.7 (S4)
E37: U1.37 (E37), U17.9 (S8)
E38: U1.38 (E38), U17.10 (S7)
E39: U1.39 (E39), U17.11 (S6)
E40: U1.40 (E40), U17.12 (S5)
E41: U1.41 (E41), U12.9 (S8)
E42: U1.42 (E42), U12.10 (S7)
E43: U1.43 (E43), U12.11 (S6)
E44: U1.44 (E44), U12.12 (S5)
E45: U1.45 (E45), U17.4 (S1)
E46: U1.46 (E46), U17.5 (S2)
E47: U1.47 (E47), U17.6 (S3)
E48: U1.48 (E48), U17.7 (S4)
E49: U1.49 (E49), U11.4 (S1)
E50: U1.50 (E50), U11.6 (S3)
E51: U1.51 (E51), U11.9 (S8)
E52: U1.52 (E52), U11.11 (S6)
E53: U1.53 (E53), U18.5 (S2)
E54: U1.54 (E54), U18.7 (S4)
E55: U1.55 (E55), U18.11 (S6)
E56: U1.56 (E56), U18.12 (S5)
E57: U1.57 (E57), U11.5 (S2)
E58: U1.58 (E58), U11.7 (S4)
E59: U1.59 (E59), U11.10 (S7)
E60: U1.60 (E60), U11.12 (S5)
E61: U1.61 (E61), U18.4 (S1)
E62: U1.62 (E62), U18.6 (S3)
E63: U1.63 (E63), U18.9 (S8)
E64: U1.64 (E64), U18.10 (S7)
GND: C1.2, C2.2, C3.2, C4.2, C5.2, C6.2, C7.2, C8.2, C9.2, C10.2, C11.2, C12.2, C13.2, C14.2, C15.2, C16.2, C17.2, C18.2, C19.2, C20.2, C21.2, U2.8 (GND), U2.17 (TPAD), U3.8 (GND), U3.17 (TPAD), U4.8 (GND), U4.17 (TPAD), U5.8 (GND), U5.17 (TPAD), U6.8 (GND), U6.17 (TPAD), U7.3 (V-), U8.1, U8.3, U10.3 (VSS), U10.14 (GND), U11.3 (VSS), U11.14 (GND), U12.3 (VSS), U12.14 (GND), U13.3 (VSS), U13.14 (GND), U14.3 (VSS), U14.14 (GND), U15.3 (VSS), U15.14 (GND), U16.3 (VSS), U16.14 (GND), U17.3 (VSS), U17.14 (GND), U18.3 (VSS), U18.14 (GND), U19.1, U19.3, U20.2, U21.1, U21.2
unnamed: R9.1, R31.1, U9.2
unnamed: U2.9 (QH'), U3.14 (SER)
unnamed: U2.14 (SER), U4.9 (QH')
unnamed: U3.9 (QH'), U5.14 (SER)
unnamed: U5.9 (QH'), U6.14 (SER)
unnamed: R20.2, U7.1 (IN+)
unnamed: C78.1, R4.1, U7.8 (IN-)
unnamed: C78.2, R4.2, R31.2, U7.4 (Vout)
unnamed: R9.2, R20.1, U10.8 (D)
S11A0: U5.5 (QF), U11.1 (A0)
S11A1: U5.6 (QG), U11.16 (A1)
S11A2: U5.7 (QH), U11.15 (A2)
S11D: C3.1, U10.4 (S1), U11.8 (D)
S11EN: U5.4 (QE), U11.2 (EN)
S12A0: U5.1 (QB), U12.1 (A0)
S12A1: U5.2 (QC), U12.16 (A1)
S12A2: U5.3 (QD), U12.15 (A2)
S12D: C4.1, U10.5 (S2), U12.8 (D)
S12EN: U5.15 (QA), U12.2 (EN)
S13A0: U3.5 (QF), U13.1 (A0)
S13A1: U3.6 (QG), U13.16 (A1)
S13A2: U3.7 (QH), U13.15 (A2)
S13D: C12.1, U10.6 (S3), U13.8 (D)
S13EN: U3.4 (QE), U13.2 (EN)
S14A0: U3.1 (QB), U14.1 (A0)
S14A1: U3.2 (QC), U14.16 (A1)
S14A2: U3.3 (QD), U14.15 (A2)
S14D: C15.1, U10.7 (S4), U14.8 (D)
S14EN: U3.15 (QA), U14.2 (EN)
S15A0: U2.5 (QF), U15.1 (A0)
S15A1: U2.6 (QG), U15.16 (A1)
S15A2: U2.7 (QH), U15.15 (A2)
S15D: C17.1, U10.12 (S5), U15.8 (D)
S15EN: U2.4 (QE), U15.2 (EN)
S16A0: U2.1 (QB), U16.1 (A0)
S16A1: U2.2 (QC), U16.16 (A1)
S16A2: U2.3 (QD), U16.15 (A2)
S16D: C18.1, U10.11 (S6), U16.8 (D)
S16EN: U2.15 (QA), U16.2 (EN)
S17A0: U4.5 (QF), U17.1 (A0)
S17A1: U4.6 (QG), U17.16 (A1)
S17A2: U4.7 (QH), U17.15 (A2)
S17D: C7.1, U10.10 (S7), U17.8 (D)
S17EN: U4.4 (QE), U17.2 (EN)
S18A0: U4.1 (QB), U18.1 (A0)
S18A1: U4.2 (QC), U18.16 (A1)
S18A2: U4.3 (QD), U18.15 (A2)
S18D: C10.1, U10.9 (S8), U18.8 (D)
S18EN: U4.15 (QA), U18.2 (EN)
S20A0: U6.1 (QB), U10.1 (A0)
S20A1: U6.2 (QC), U10.16 (A1)
S20A2: U6.3 (QD), U10.15 (A2)
S20EN: U6.15 (QA), U10.2 (EN)
Shift_OEb: U2.13 (~OE), U3.13 (~OE), U4.13 (~OE), U5.13 (~OE), U6.13 (~OE), U20.3
Shift_RCLK: U2.12 (RCLK), U3.12 (RCLK), U4.12 (RCLK), U5.12 (RCLK), U6.12 (RCLK), U21.3
Shift_SER: U4.14 (SER), U22.1
Shift_SRCLK: U2.11 (SRCLK), U3.11 (SRCLK), U4.11 (SRCLK), U5.11 (SRCLK), U6.11 (SRCLK), U22.3
Shift_SRCLRb: U2.10 (~SRCLR), U3.10 (~SRCLR), U4.10 (~SRCLR), U5.10 (~SRCLR), U6.10 (~SRCLR), U22.2
guard_ring: U7.2 (GRD), U7.7 (GRD), U8.2, U9.1, U9.3, U19.2

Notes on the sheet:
P4P ADG708BRUZ TSSOP-16
EN 2.4Vmin
1.8-5.5V
Electrode Array 64 pads
Evaluate 2 types of analog mux.

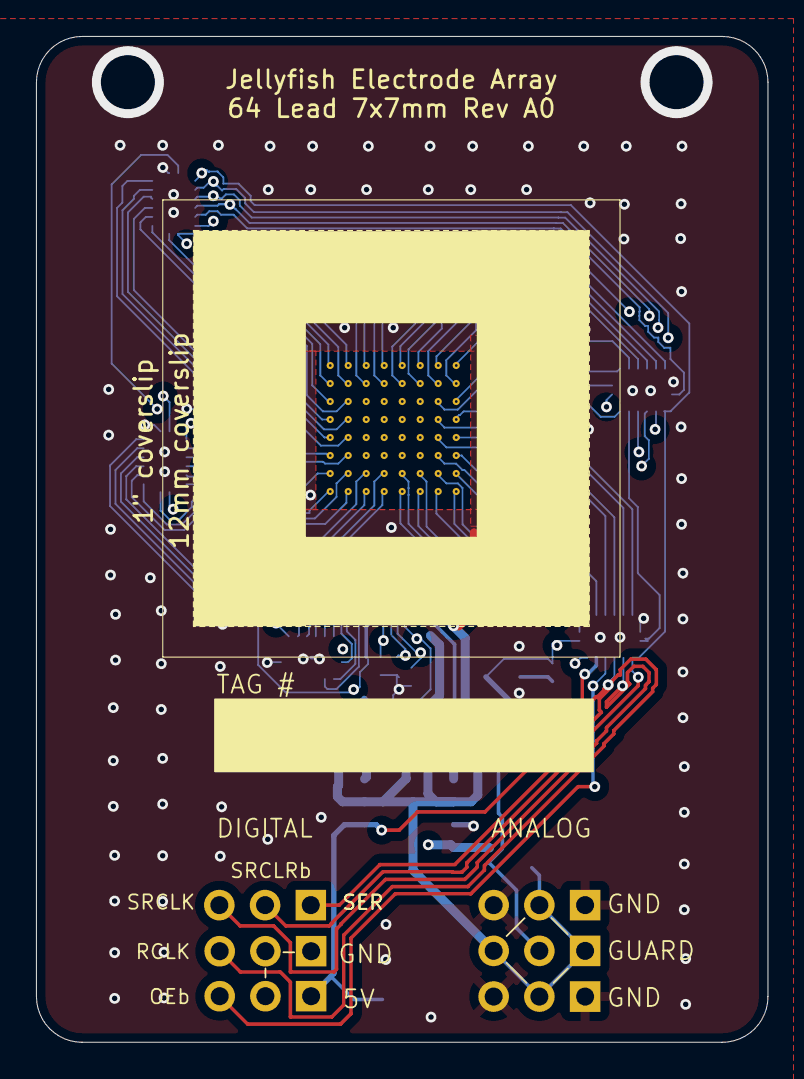
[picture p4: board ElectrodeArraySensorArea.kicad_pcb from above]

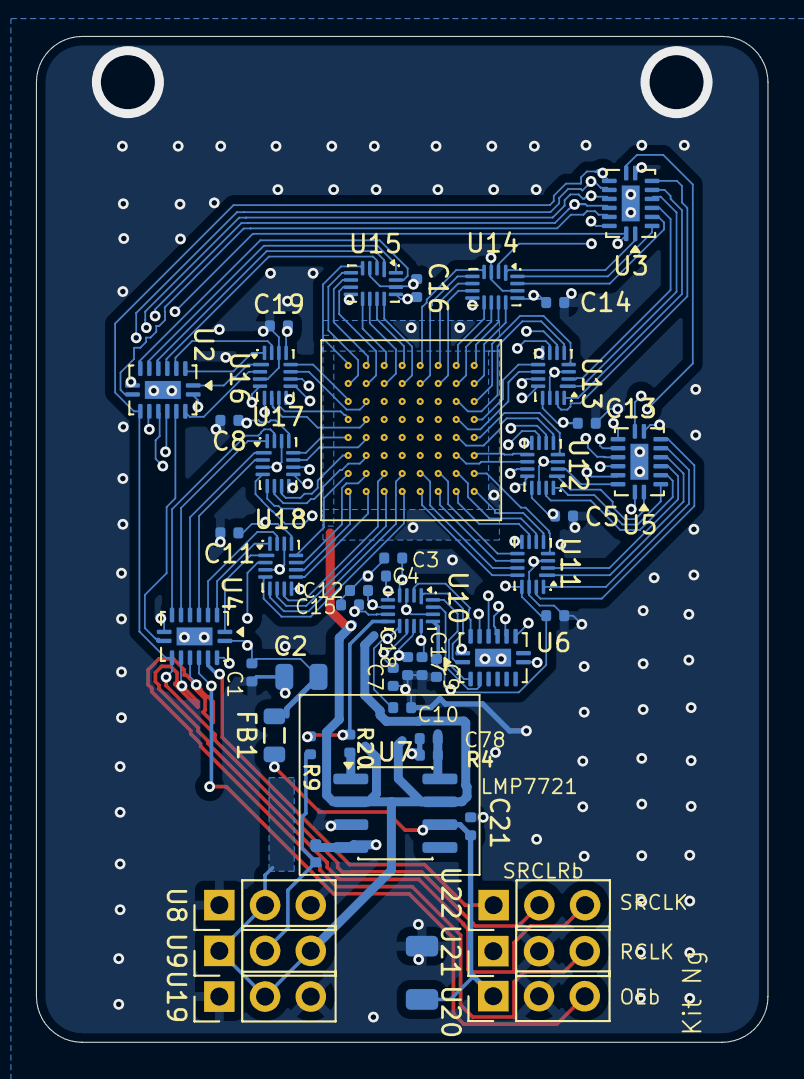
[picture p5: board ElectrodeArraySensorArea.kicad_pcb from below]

Board: 4 copper layers, 40.6 x 55.9 mm, 49 parts (48 on the bottom side), 126 nets.

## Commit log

2025-12-10 Initial commit
    Add fabbed board files for KiCad.
    [ElectrodeArrayPCB-B_Cu.gbr, ElectrodeArrayPCB-B_Mask.gbr, ElectrodeArrayPCB-B_Paste.gbr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]
2025-12-10 Create README.md for Jellyfish Data Acquisition Board
    Added initial documentation for the Jellyfish Data Acquisition Board project, including hardware details for the Electrode and Digitizer boards.
